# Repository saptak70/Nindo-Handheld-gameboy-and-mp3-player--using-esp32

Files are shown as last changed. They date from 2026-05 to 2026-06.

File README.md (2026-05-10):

# RetroHand — ESP32-S3 Retro Gaming + BT Audio Handheld

A custom handheld device built from scratch — PCB, firmware, 
and enclosure. Plays NES/DOOM, streams audio to BT headphones.

## Features
- ESP32-S3-WROOM-1 N8R8 (dual core, BT5, 8MB PSRAM)
- ST7789V3 1.69" 240×280 SPI display
- PCM5102A I2S DAC + 3.5mm jack + BT A2DP
- MicroSD for ROMs and music
- LiPo battery with TP4056 charging + DW01A protection
- Custom KiCad PCB + 3D printed enclosure

## Photos
[photos here]

## Hardware
[link to schematic PDF]
[link to BOM]

## Build Guide
[step by step]

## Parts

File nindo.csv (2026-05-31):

Reference | Qty | Value | DNP | Exclude from BOM | Exclude from Board | Footprint | Datasheet
8205A1 | 1 |  |  |  |  | Package_TO_SOT_SMD:SOT-23-6
C1,C2 | 2 | 0.1u
C3,C4,C5 | 3 | 10u
C6 | 1 | 100n
J1 | 1 | Micro_SD_Card_Det1 |  |  |  | Connector_Card:microSD_HC_Hirose_DM3AT-SF-PEJM5 | https://datasheet.lcsc.com/lcsc/2110151630_XKB-Connectivity-XKTF-015-N_C381082.pdf
J2 | 1 | USB_C_Receptacle_USB2.0_16P |  |  |  | Connector_USB:USB_C_Receptacle_G-Switch_GT-USB-7010ASV | https://www.usb.org/sites/default/files/documents/usb_type-c.zip
J3 | 1 | Conn_01x08_Pin |  |  |  | Connector_Harwin:Harwin_M20-89008xx_1x08_P2.54mm_Horizontal
J4 | 1 | AudioJack3 |  |  |  | Connector_Audio:Jack_3.5mm_CUI_SJ1-3523N_Horizontal
R1 | 1 | 1K2
R2,R3 | 2 | 5K1
R4 | 1 | 1k
R5 | 1 | 100
R6,R7 | 2 | 10k
SW1,SW2,SW3,SW4,SW5,SW6,SW7 | 7 | SW_MEC_5G |  |  |  | Button_Switch_SMD:SW_MEC_5GSH9 | https://www.apem.com/medias/download/MEC_switches_serie_MULTIMEC5G.pdf
U1 | 1 | PCM5102A |  |  |  | Package_SO:TSSOP-20_4.4x6.5mm_P0.65mm | https://www.ti.com/lit/ds/symlink/pcm5102a.pdf
U2 | 1 | ESP32-S3-WROOM-1 |  |  |  | RF_Module:ESP32-S3-WROOM-1 | https://www.espressif.com/sites/default/files/documentation/esp32-s3-wroom-1_wroom-1u_datasheet_en.pdf
U3 | 1 | TP4056-42-ESOP8 |  |  |  | Package_SO:SOIC-8-1EP_3.9x4.9mm_P1.27mm_EP2.41x3.3mm_ThermalVias | https://www.lcsc.com/datasheet/lcsc_datasheet_2410121619_TOPPOWER-Nanjing-Extension-Microelectronics-TP4056-42-ESOP8_C16581.pdf
U4 | 1 | DW01A |  |  |  | Package_TO_SOT_SMD:SOT-23-6 | https://hmsemi.com/downfile/DW01A.PDF
U5 | 1 | ME6211C33M5 |  |  |  | Package_TO_SOT_SMD:SOT-23-5 | https://www.lcsc.com/datasheet/lcsc_datasheet_2304140030_MICRONE-Nanjing-Micro-One-Elec-ME6211C33R5G_C235316.pdf

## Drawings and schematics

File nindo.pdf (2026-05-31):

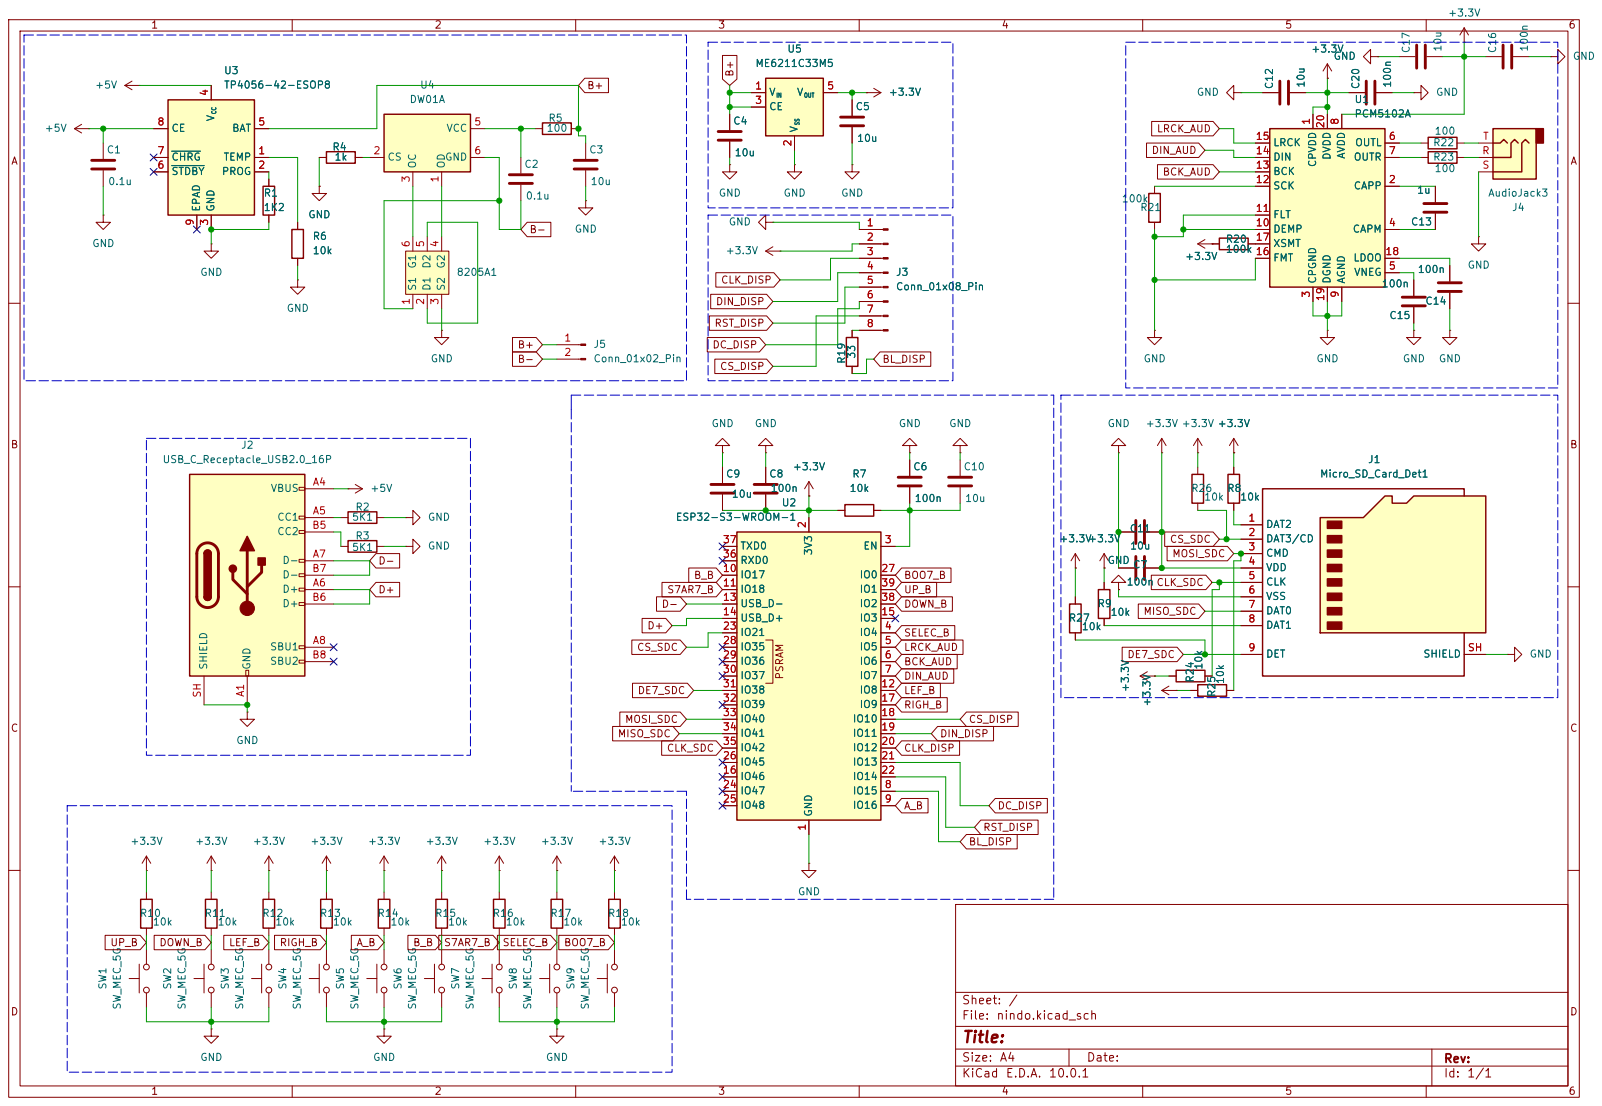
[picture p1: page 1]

SCK 12 BCK 13 DIN 14 LRCK 15

GND | J3Conn_01x08_Pin 1

Size: A4 | Rev:
KiCad E.D.A. 10.0.1 | Id: 1/1

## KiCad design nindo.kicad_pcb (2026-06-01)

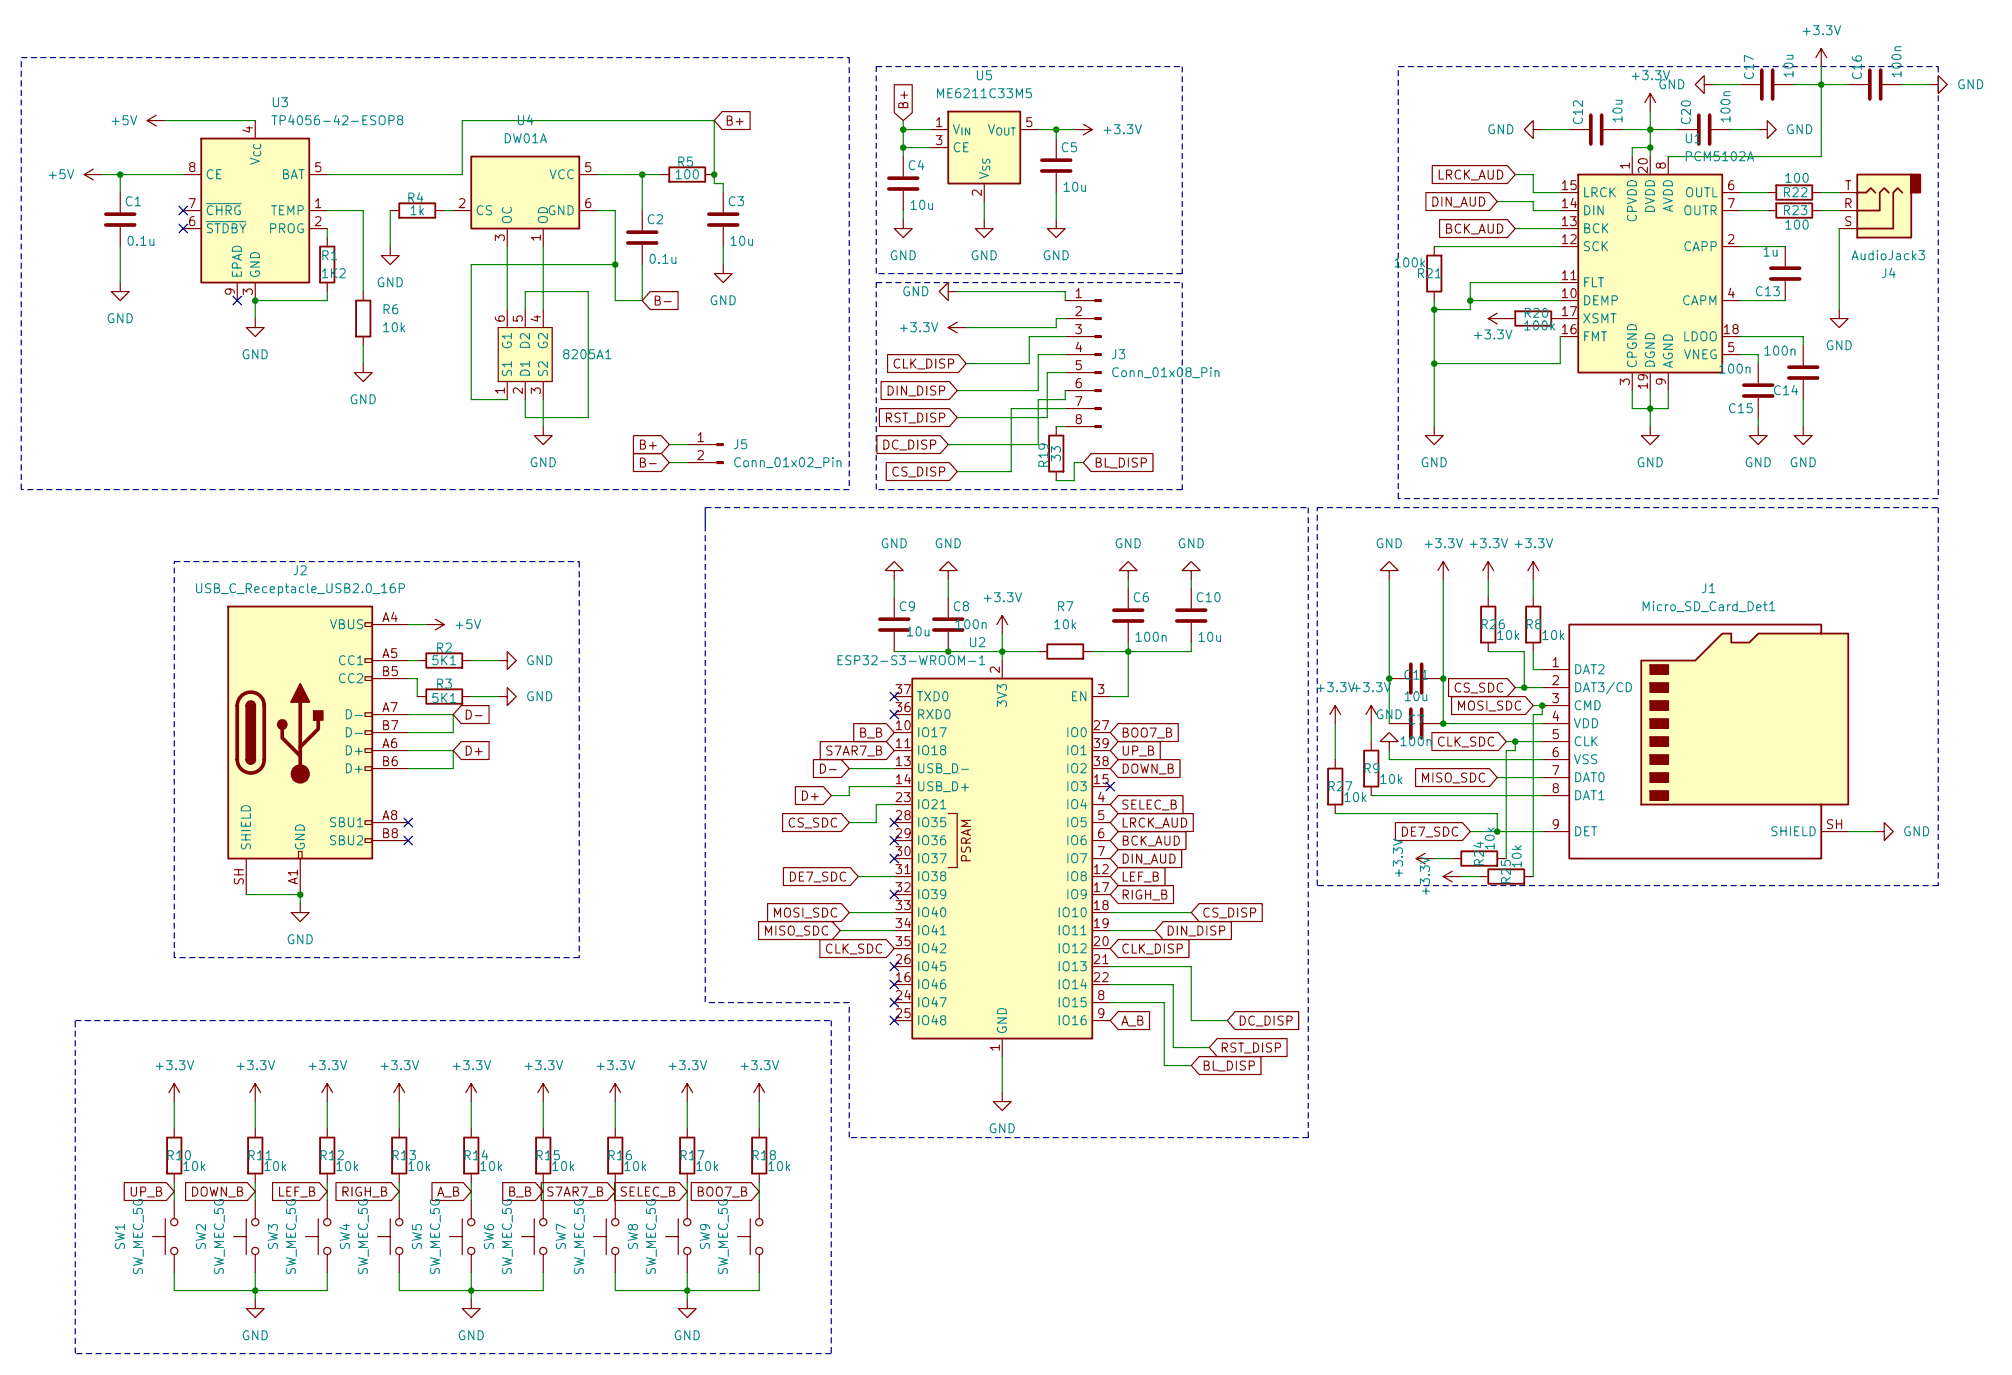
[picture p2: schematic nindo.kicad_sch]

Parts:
8205A1: SOT-23-6
C1, C2: 0.1u; C_1206_3216Metric_Pad1.33x1.80mm_HandSolder
C3, C4, C5, C9, C10, C11, C12, C17: 10u; C_1206_3216Metric_Pad1.33x1.80mm_HandSolder
C6, C7, C8, C14, C15, C16, C20: 100n; C_1206_3216Metric_Pad1.33x1.80mm_HandSolder
C13: 1u; C_1206_3216Metric_Pad1.33x1.80mm_HandSolder
J1: Micro_SD_Card_Det1; microSD_HC_Hirose_DM3AT-SF-PEJM5
J2: USB_C_Receptacle_USB2.0_16P; USB_C_Receptacle_G-Switch_GT-USB-7010ASV
J3: Conn_01x08_Pin; Harwin_M20-89008xx_1x08_P2.54mm_Horizontal
J4: AudioJack3; Jack_3.5mm_CUI_SJ1-3523N_Horizontal
J5: Conn_01x02_Pin; JWT_A3963_1x02_P3.96mm_Vertical
R1: 1K2; R_1206_3216Metric_Pad1.30x1.75mm_HandSolder
R2, R3: 5K1; R_1206_3216Metric_Pad1.30x1.75mm_HandSolder
R4: 1k; R_1206_3216Metric_Pad1.30x1.75mm_HandSolder
R5, R22, R23: 100; R_1206_3216Metric_Pad1.30x1.75mm_HandSolder
R6, R7, R8, R9, R10, R11, R12, R13, R14, R15, R16, R17, R18, R24, R25, R26, R27: 10k; R_1206_3216Metric_Pad1.30x1.75mm_HandSolder
R19: 33; R_1206_3216Metric_Pad1.30x1.75mm_HandSolder
R20, R21: 100k; R_1206_3216Metric_Pad1.30x1.75mm_HandSolder
SW1, SW2, SW3, SW4, SW5, SW6, SW7, SW8, SW9: SW_MEC_5G; SW_MEC_5GSH9
U1: PCM5102A; TSSOP-20_4.4x6.5mm_P0.65mm
U2: ESP32-S3-WROOM-1
U3: TP4056-42-ESOP8; SOIC-8-1EP_3.9x4.9mm_P1.27mm_EP2.41x3.3mm_ThermalVias
U4: DW01A; SOT-23-6
U5: ME6211C33M5; SOT-23-5

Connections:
+3.3V: C5.1, C7.2, C8.2, C9.2, C11.2, C12.2, C16.1, C17.2, C20.1, J1.4 (VDD), J3.2, R7.1, R8.1, R9.1, R10.1, R11.1, R12.1, R13.1, R14.1, R15.1, R16.1, R17.1, R18.1, R20.2, R24.1, R25.1, R26.1, R27.1, U1.1 (CPVDD), U1.8 (AVDD), U1.20 (DVDD), U2.2 (3V3), U5.5 (V_{OUT})
+5V: C1.1, J2.A4 (VBUS), J2.A9 (VBUS), J2.B4 (VBUS), J2.B9 (VBUS), U3.4 (V_{CC}), U3.8 (CE)
A_B: R14.2, SW5.3 (B), SW5.4 (B), U2.9 (IO16)
B+: C3.1, C4.1, J5.1, R5.1, U3.5 (BAT), U5.1 (V_{IN}), U5.3 (CE)
B-: 8205A1.1 (S1), C2.2, J5.2, U4.6 (GND)
BCK_AUD: U1.13 (BCK), U2.6 (IO6)
BL_DISP: R19.2, U2.8 (IO15)
BOO7_B: R18.2, SW9.3 (B), SW9.4 (B), U2.27 (IO0)
B_B: R15.2, SW6.3 (B), SW6.4 (B), U2.10 (IO17)
CLK_DISP: J3.3, U2.20 (IO12)
CLK_SDC: J1.5 (CLK), R24.2, U2.35 (IO42)
CS_DISP: J3.7, U2.18 (IO10)
CS_SDC: J1.2 (DAT3/CD), R26.2, U2.23 (IO21)
D+: J2.A6 (D+), J2.B6 (D+), U2.14 (USB_D+)
D-: J2.A7 (D-), J2.B7 (D-), U2.13 (USB_D-)
DC_DISP: J3.6, U2.21 (IO13)
DE7_SDC: J1.9 (DET), R27.2, U2.31 (IO38)
DIN_AUD: U1.14 (DIN), U2.7 (IO7)
DIN_DISP: J3.4, U2.19 (IO11)
DOWN_B: R11.2, SW2.3 (B), SW2.4 (B), U2.38 (IO2)
GND: 8205A1.3 (S2), C1.2, C3.2, C4.2, C5.2, C6.1, C7.1, C8.1, C9.1, C10.1, C11.1, C12.1, C14.1, C15.1, C16.2, C17.1, C20.2, J1.6 (VSS), J1.SH (SHIELD), J2.A1 (GND), J2.A12 (GND), J2.B1 (GND), J2.B12 (GND), J2.SH (SHIELD), J3.1, J4.S, R1.2, R2.2, R3.2, R4.2, R6.2, R21.1, SW1.1 (A), SW1.2 (A), SW2.1 (A), SW2.2 (A), SW3.1 (A), SW3.2 (A), SW4.1 (A), SW4.2 (A), SW5.1 (A), SW5.2 (A), SW6.1 (A), SW6.2 (A), SW7.1 (A), SW7.2 (A), SW8.1 (A), SW8.2 (A), SW9.1 (A), SW9.2 (A), U1.3 (CPGND), U1.9 (AGND), U1.10 (DEMP), U1.11 (FLT), U1.16 (FMT), U1.19 (DGND), U2.1 (GND), U2.40 (GND), U2.41 (GND), U3.3 (GND), U5.2 (V_{SS})
LEF_B: R12.2, SW3.3 (B), SW3.4 (B), U2.12 (IO8)
LRCK_AUD: U1.15 (LRCK), U2.5 (IO5)
MISO_SDC: J1.7 (DAT0), U2.34 (IO41)
MOSI_SDC: J1.3 (CMD), R25.2, U2.33 (IO40)
unnamed: 8205A1.2 (D1), 8205A1.5 (D2)
unnamed: 8205A1.6 (G1), U4.3 (OC)
unnamed: 8205A1.4 (G2), U4.1 (OD)
unnamed: J1.8 (DAT1), R9.2
unnamed: J1.1 (DAT2), R8.2
unnamed: J2.A5 (CC1), R2.1
unnamed: J2.B5 (CC2), R3.1
unnamed: J3.8, R19.1
unnamed: J4.R, R23.1
unnamed: J4.T, R22.1
unnamed: C13.1, U1.4 (CAPM)
unnamed: C13.2, U1.2 (CAPP)
unnamed: C14.2, U1.18 (LDOO)
unnamed: R22.2, U1.6 (OUTL)
unnamed: R23.2, U1.7 (OUTR)
unnamed: R21.2, U1.12 (SCK)
unnamed: C15.2, U1.5 (VNEG)
unnamed: R20.1, U1.17 (XSMT)
unnamed: C6.2, C10.2, R7.2, U2.3 (EN)
unnamed: R1.1, U3.2 (PROG)
unnamed: R6.1, U3.1 (TEMP)
unnamed: R4.1, U4.2 (CS)
unnamed: C2.1, R5.2, U4.5 (VCC)
RIGH_B: R13.2, SW4.3 (B), SW4.4 (B), U2.17 (IO9)
RST_DISP: J3.5, U2.22 (IO14)
S7AR7_B: R16.2, SW7.3 (B), SW7.4 (B), U2.11 (IO18)
SELEC_B: R17.2, SW8.3 (B), SW8.4 (B), U2.4 (IO4)
UP_B: R10.2, SW1.3 (B), SW1.4 (B), U2.39 (IO1)

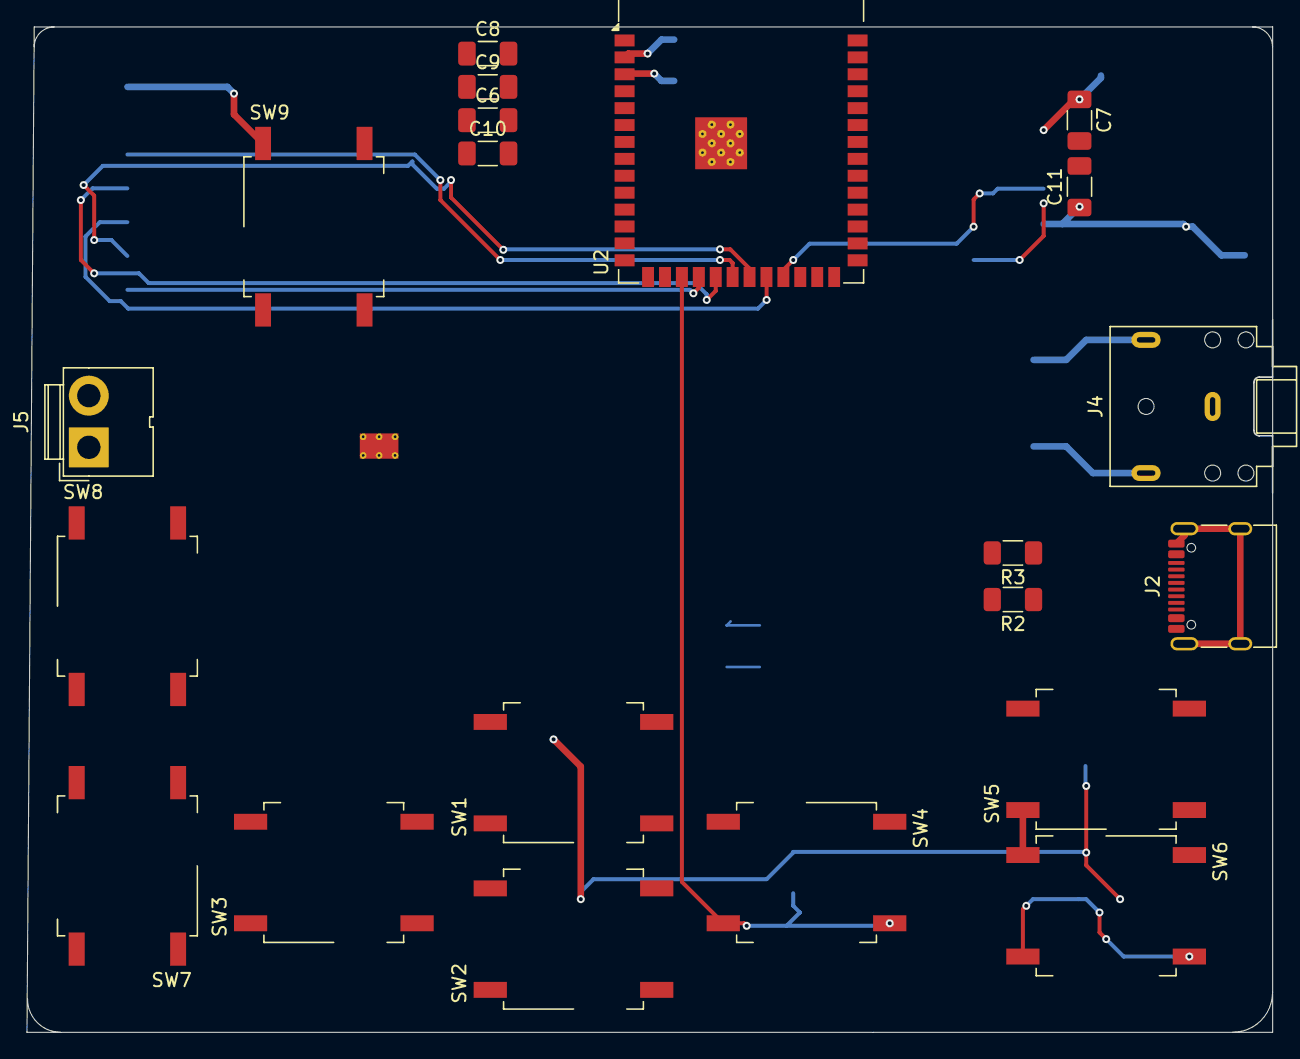
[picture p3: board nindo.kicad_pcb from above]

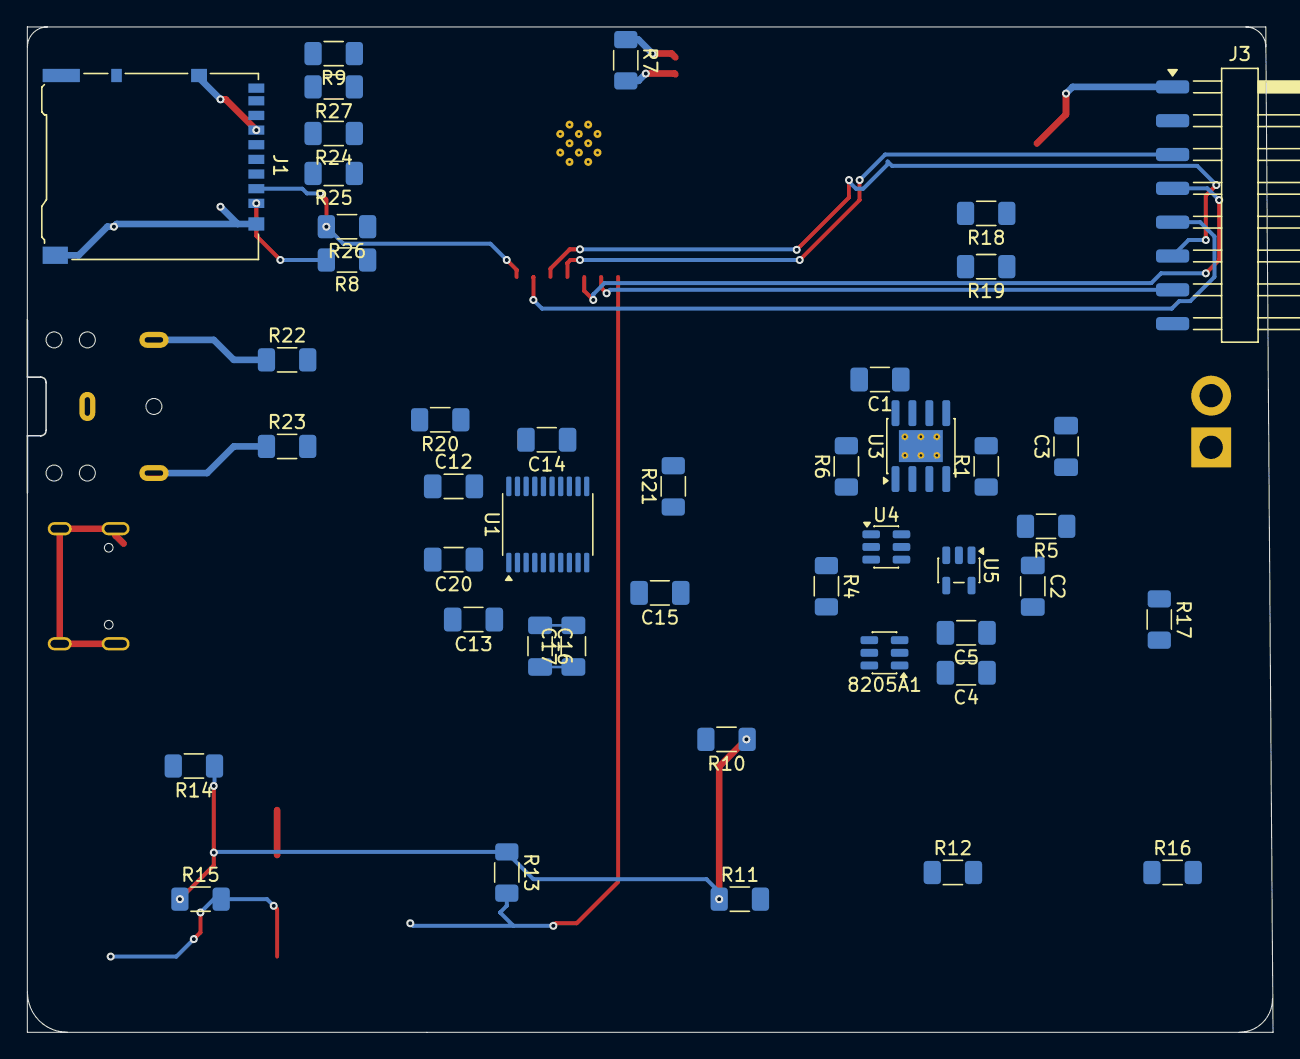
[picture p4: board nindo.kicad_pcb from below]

Board: 2 copper layers, 93.5 x 75.5 mm, 65 parts (44 on the bottom side), 53 nets.
